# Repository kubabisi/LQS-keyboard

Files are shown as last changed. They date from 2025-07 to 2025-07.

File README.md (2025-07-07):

# LQS keyboard
**L**ow profile **Q**uiet **S**plit keyboard

## Why have I decided to build a keyboard?
A few years ago I received an 80% mechanical keyboard as a Christmas gift. It has been my daily driver since then.
But it has two issues:
1. It is too big and chunky to travel with or take it to school.
2. It is too loud. While it is quieter than some mechanical keyboards, you can easily hear it from the other side of my flat.

Since then Youtube algorithm has introduced me into the custom keyboard rabbit hole.
I've built a simple one using 3d printed parts and handwiring. It worked, but it was thick and after a few weeks it started to slowly break apart. First random solder joints started breaking, then the case cracked.

I wanted to build a proper keyboard, but I was too lazy to do it.
Highway gave me the motivation that I needed to finally do it.

## CAD model
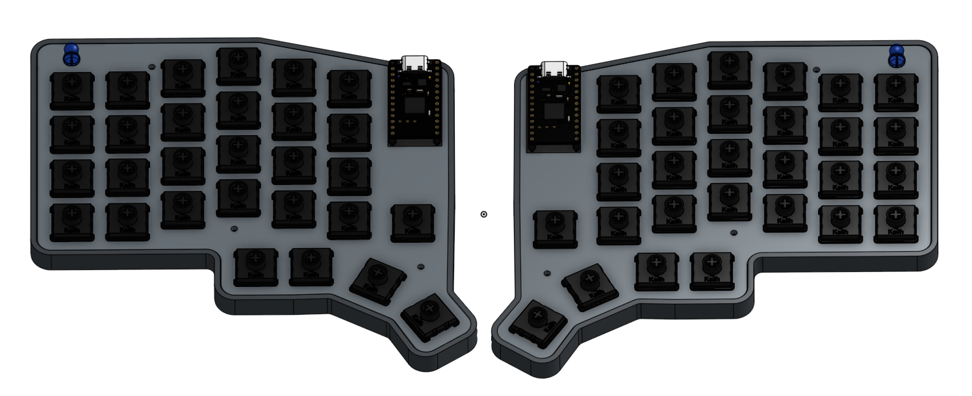
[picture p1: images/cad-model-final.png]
cad model

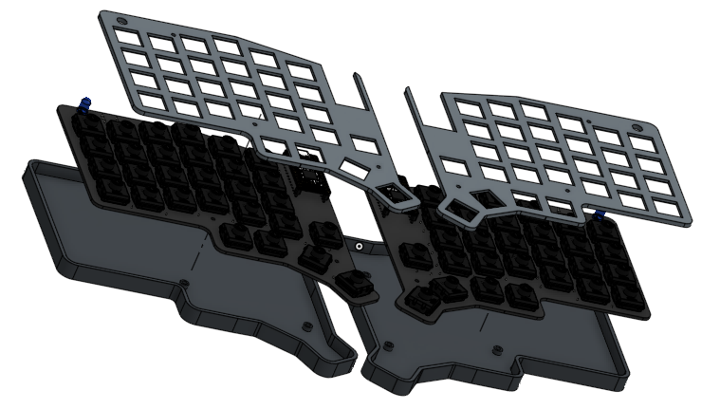
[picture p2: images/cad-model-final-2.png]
exploded cad model

[this model in Onshape](https://cad.onshape.com/documents/f682215273ff2081de69d414/w/20c4360147d88d6d7c704790/e/f61e22c6f2ff044978f79a00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)

## Switch layout
Switch layout was inspired by two keyboards I like: ZSA Voyager and Sofle
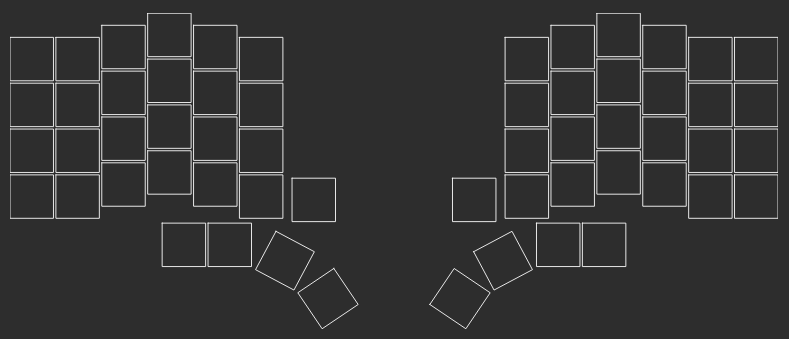
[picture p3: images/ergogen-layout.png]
layout in ergogen


## Schematic
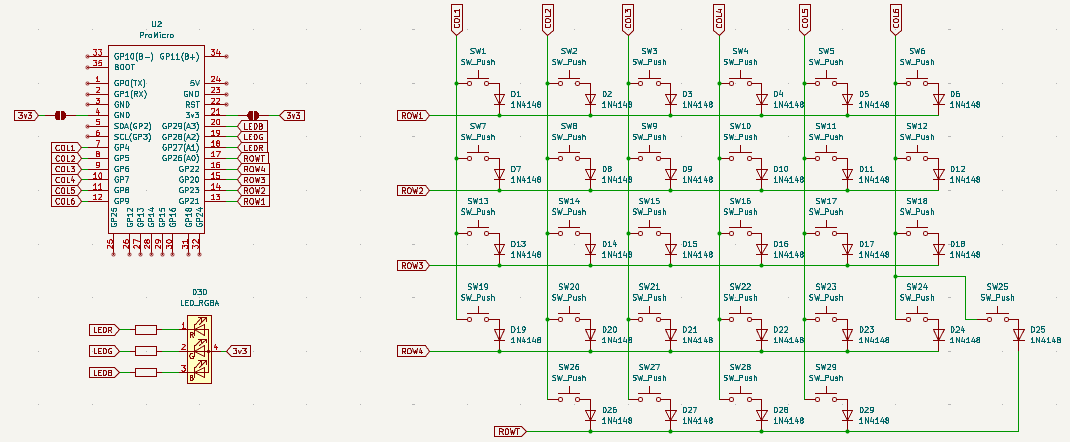
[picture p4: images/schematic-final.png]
keyboard half schematic


## PCB
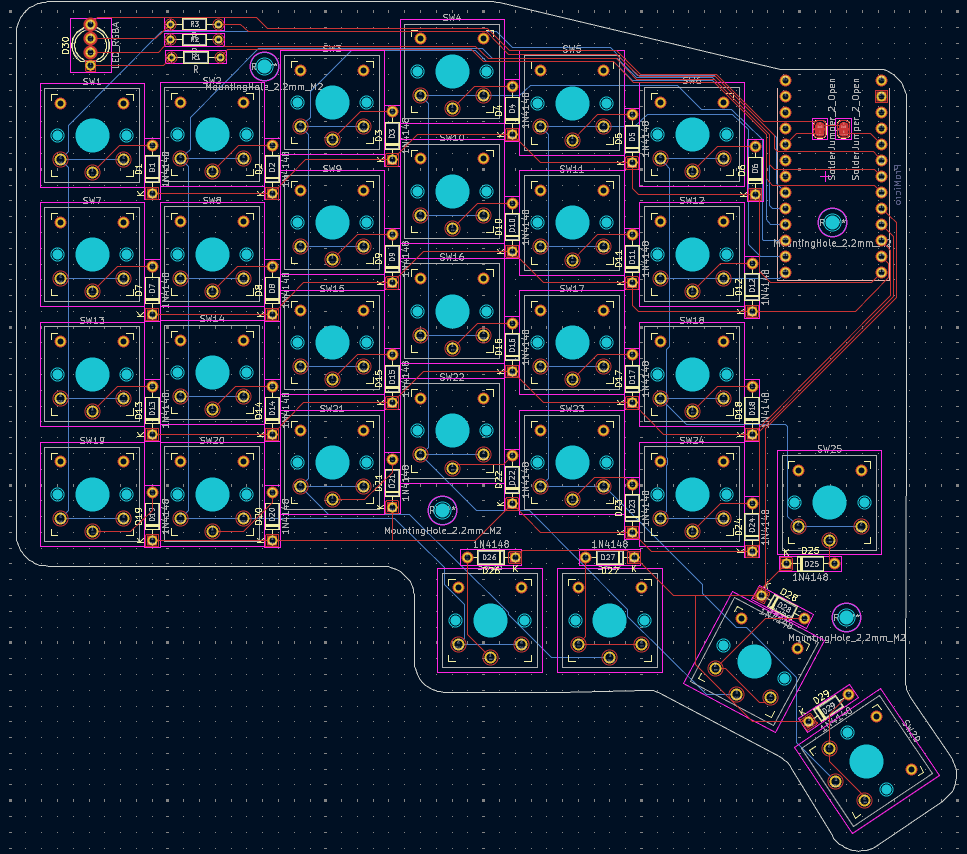
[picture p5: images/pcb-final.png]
keyboard half pcb


## Case
Case for this keyboard can be 3d printed. Stl files are located in [this folder](3d-models/case)

## BOM

| Part | Quantity | Cost(PLN) | Cost (USD) | Store | Link |
| --- | --- | --- | --- | --- | --- |
| Kailh Deep Sea Whale mini switches | 58 | 113.99 | 29.70 | Aliexpress | https://pl.aliexpress.com/item/1005008927866337.html |
| Pro Micro NRF52840 | 2 | 26.78 | 7.04 | Aliexpress | https://pl.aliexpress.com/item/1005006599766097.html |
| 301230 lipo battery | 2 | 45.25 | 11.70 | Allegro.pl | https://allegro.pl/oferta/akumulator-litowo-polimerowy-110mah-3-7v-phr-2-bk-301230-17500532114 |
| 1n4148 diodes | 58 | 5.55 | 1.47 | Aliexpress | https://pl.aliexpress.com/item/4000142272546.html |
| RGB common anode 5mm led | 2 | 3.99 | 1.05 | Aliexpress | https://pl.aliexpress.com/item/4000225253691.html |
| pin sockets | 52 pins - 2 rows | 7.10 | 1.87 | Aliexpress | https://pl.aliexpress.com/item/10000000838267.html |
| PCB | 5 | 41.80 | 11.60 | JLCPCB | https://jlcpcb.com/ |
| M2 6mm flat head screws | 8 | 3.62 | 0.96 | Aliexpress | https://pl.aliexpress.com/item/1005005270702287.html | 
| M2 3x3mm heat inserts | 8 | 5.6 | 1.47 | Aliexpress | https://pl.aliexpress.com/item/1005008295045821.html |
| resistors for leds | 6 | ~4 | ~1 | |  |
| keycap set | 1 | ~120 | ~35 | | |
| 3d printed case | 2 | | | | |

Total (excluding shipping): ~380 PLN / ~$105 USD

I already have keycaps and resistors. My brother has a 3d printer at home.

Total excluding parts I have, with shipping:
- $66.77 + $21.50 (JLCPCB shipping) + $0 (Aliexpress Choice free shipping) = $88.27
- 253,61zł + 77,63zł + 0zł = 331.24zł

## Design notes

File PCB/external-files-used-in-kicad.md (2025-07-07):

# footprints
- switch: https://github.com/siderakb/key-switches.pretty
- pro micro: https://github.com/Biacco42/ProMicroKiCad

# 3d models
- switch: https://github.com/koktoh/keyswitch_model
- nice!nano: https://grabcad.com/library/nice-nano-v2-1
- round pin socket: https://grabcad.com/library/straight-round-female-pin-header-2-54-mm-1

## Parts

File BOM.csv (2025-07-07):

part | quantity | cost(USD) | link
Kailh Deep Sea Whale mini switch | 58 | 29.70 | https://pl.aliexpress.com/item/1005008927866337.html
Pro Micro NRF52840 | 2 | 7.04 | https://pl.aliexpress.com/item/1005006599766097.html
301230 LiPo battery | 2 | 11.70 | https://allegro.pl/oferta/akumulator-litowo-polimerowy-110mah-3-7v-phr-2-bk-301230-17500532114
1n4148 diode | 58 | 1.47 | https://pl.aliexpress.com/item/4000142272546.html
RGB 5mm diode | 2 | 1.05 | https://pl.aliexpress.com/item/4000225253691.html
pin socket | 2 | 1.87 | https://pl.aliexpress.com/item/10000000838267.html
PCB | 5 | 11.60 | https://jlcpcb.com/
M2 6mm flat screw | 8 | 0.96 | https://pl.aliexpress.com/item/1005005270702287.html
M2 3x3mm heat insert | 8 | 1.47 | https://pl.aliexpress.com/item/1005008295045821.html
resistor | 6 | 1
keycap set | 1 | 35

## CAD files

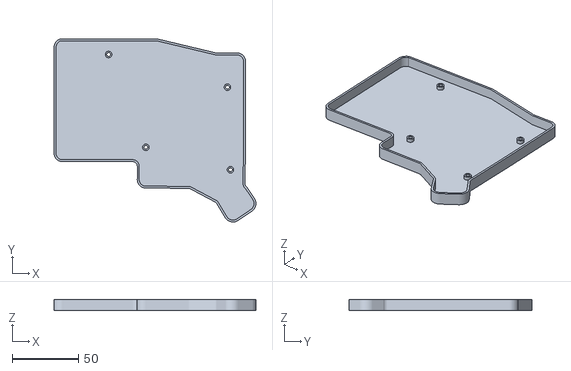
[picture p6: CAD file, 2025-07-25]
3d-models/case/left-shell.stl
152.9 x 138.6 x 8.50

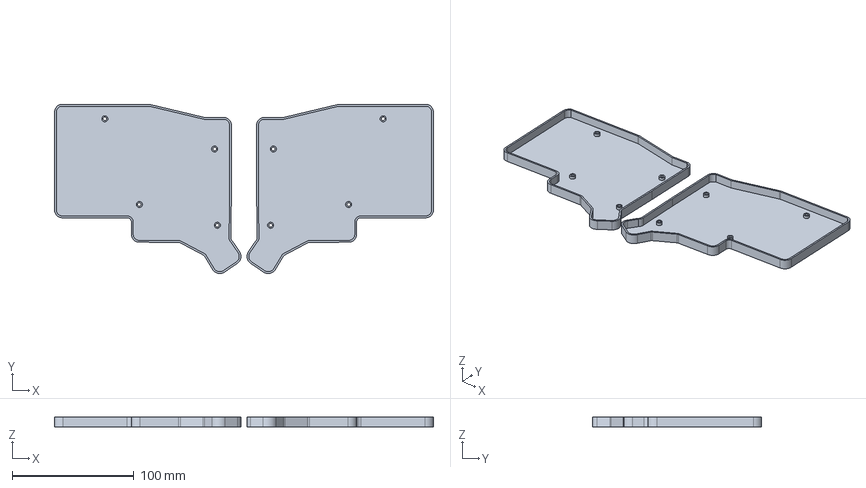
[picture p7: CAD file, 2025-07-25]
3d-models/step-files/shells.step
310.7 x 138.6 x 8.50 mm

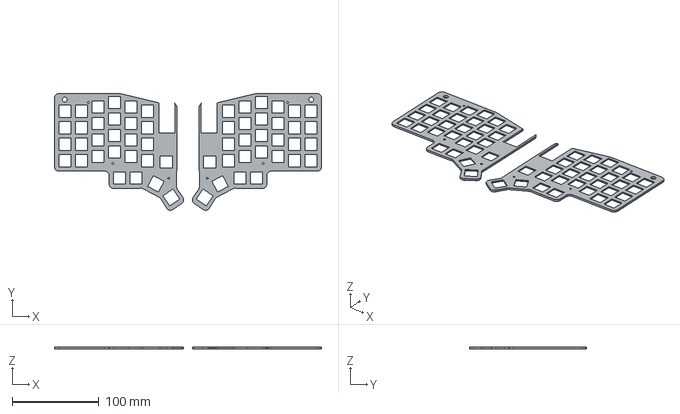
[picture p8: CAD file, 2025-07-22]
3d-models/step-files/plates.step
307.7 x 134.5 x 2.20 mm

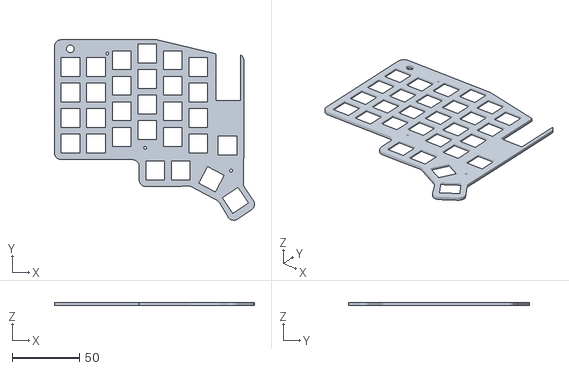
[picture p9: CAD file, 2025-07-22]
3d-models/case/left-plate.stl
148.9 x 134.5 x 2.20

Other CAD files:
3d-models/case/right-shell.stl
3d-models/case/right-plate.stl

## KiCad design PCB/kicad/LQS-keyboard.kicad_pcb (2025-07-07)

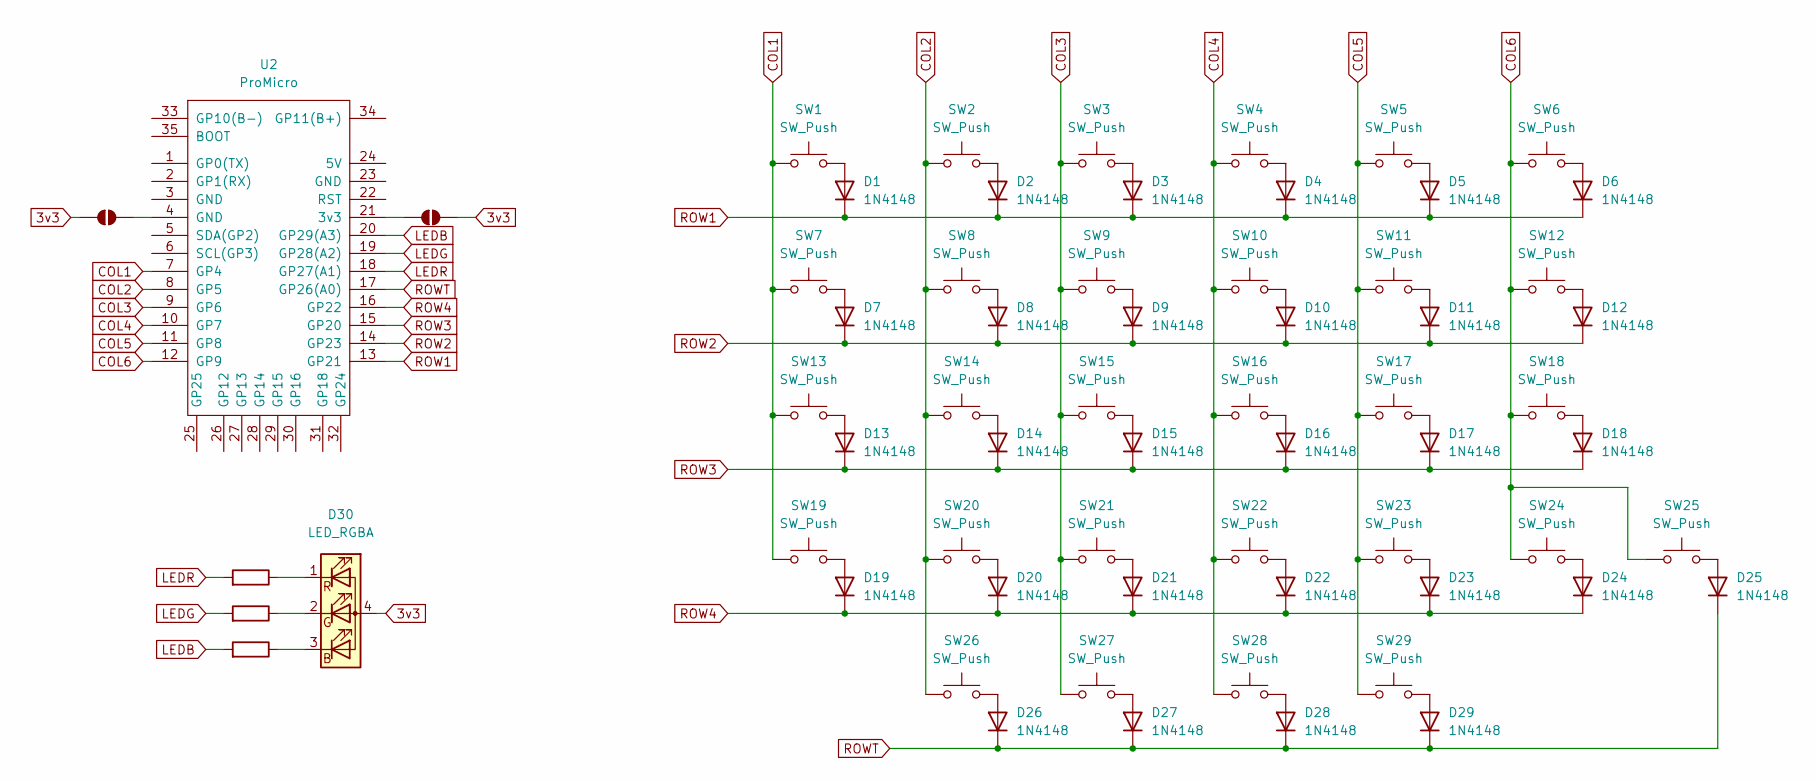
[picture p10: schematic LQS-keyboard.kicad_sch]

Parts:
D1, D2, D3, D4, D5, D6, D7, D8, D9, D10, D11, D12, D13, D14, D15, D16, D17, D18, D19, D20, D21, D22, D23, D24, D25, D26, D27, D28, D29: 1N4148; D_DO-35_SOD27_P7.62mm_Horizontal
D30: LED_RGBA; LED_D5.0mm-4_RGB
JP1, JP2: SolderJumper_2_Open; SolderJumper-2_P1.3mm_Open_RoundedPad1.0x1.5mm
R1, R2, R3: R; R_Axial_DIN0204_L3.6mm_D1.6mm_P7.62mm_Horizontal
SW1, SW2, SW3, SW4, SW5, SW6, SW7, SW8, SW9, SW10, SW11, SW12, SW13, SW14, SW15, SW16, SW17, SW18, SW19, SW20, SW21, SW22, SW23, SW24, SW25, SW26, SW27, SW28, SW29: SW_Push; SW_Kailh_Choc_V1V2_THT_Hybrid_doubleside
U2: ProMicro; TheOneProMicro

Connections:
3v3: D30.4 (A), JP1.2 (B), JP2.2 (B)
COL1: SW1.2, SW7.2, SW13.2, SW19.2, U2.7 (GP4)
COL2: SW2.2, SW8.2, SW14.2, SW20.2, SW26.2, U2.8 (GP5)
COL3: SW3.2, SW9.2, SW15.2, SW21.2, SW27.1, U2.9 (GP6)
COL4: SW4.2, SW10.2, SW16.2, SW22.2, SW28.1, U2.10 (GP7)
COL5: SW5.2, SW11.2, SW17.2, SW23.2, SW29.1, U2.11 (GP8)
COL6: SW6.2, SW12.2, SW18.2, SW24.2, SW25.2, U2.12 (GP9)
LEDB: R3.2, U2.20 (GP29(A3))
LEDG: R2.2, U2.19 (GP28(A2))
LEDR: R1.2, U2.18 (GP27(A1))
unnamed: D1.2 (A), SW1.1
unnamed: D2.2 (A), SW2.1
unnamed: D3.2 (A), SW3.1
unnamed: D4.2 (A), SW4.1
unnamed: D5.2 (A), SW5.1
unnamed: D6.2 (A), SW6.1
unnamed: D7.2 (A), SW7.1
unnamed: D8.2 (A), SW8.1
unnamed: D9.2 (A), SW9.1
unnamed: D10.2 (A), SW10.1
unnamed: D11.2 (A), SW11.1
unnamed: D12.2 (A), SW12.1
unnamed: D13.2 (A), SW13.1
unnamed: D14.2 (A), SW14.1
unnamed: D15.2 (A), SW15.1
unnamed: D16.2 (A), SW16.1
unnamed: D17.2 (A), SW17.1
unnamed: D18.2 (A), SW18.1
unnamed: D19.2 (A), SW19.1
unnamed: D20.2 (A), SW20.1
unnamed: D21.2 (A), SW21.1
unnamed: D22.2 (A), SW22.1
unnamed: D23.2 (A), SW23.1
unnamed: D24.2 (A), SW24.1
unnamed: D25.2 (A), SW25.1
unnamed: D26.2 (A), SW26.1
unnamed: D27.2 (A), SW27.2
unnamed: D28.2 (A), SW28.2
unnamed: D29.2 (A), SW29.2
unnamed: D30.3 (BK), R3.1
unnamed: D30.2 (GK), R2.1
unnamed: D30.1 (RK), R1.1
unnamed: JP1.1 (A), U2.4 (GND)
unnamed: JP2.1 (A), U2.21 (3v3)
ROW1: D1.1 (K), D2.1 (K), D3.1 (K), D4.1 (K), D5.1 (K), D6.1 (K), U2.13 (GP21)
ROW2: D7.1 (K), D8.1 (K), D9.1 (K), D10.1 (K), D11.1 (K), D12.1 (K), U2.14 (GP23)
ROW3: D13.1 (K), D14.1 (K), D15.1 (K), D16.1 (K), D17.1 (K), D18.1 (K), U2.15 (GP20)
ROW4: D19.1 (K), D20.1 (K), D21.1 (K), D22.1 (K), D23.1 (K), D24.1 (K), U2.16 (GP22)
ROWT: D25.1 (K), D26.1 (K), D27.1 (K), D28.1 (K), D29.1 (K), U2.17 (GP26(A0))

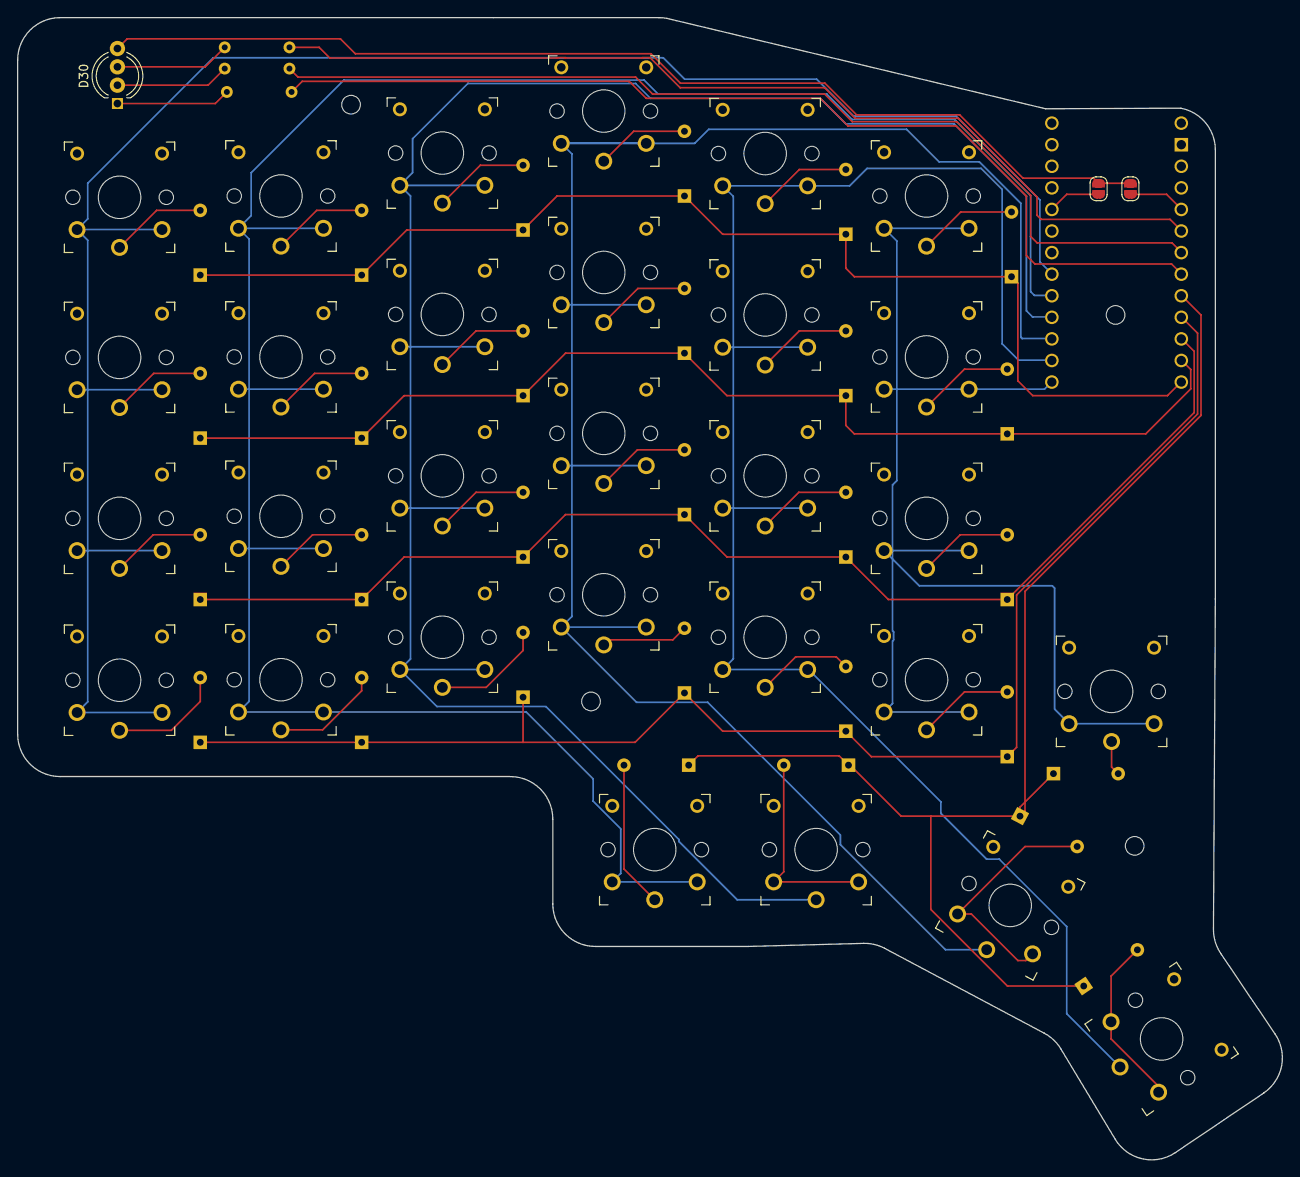
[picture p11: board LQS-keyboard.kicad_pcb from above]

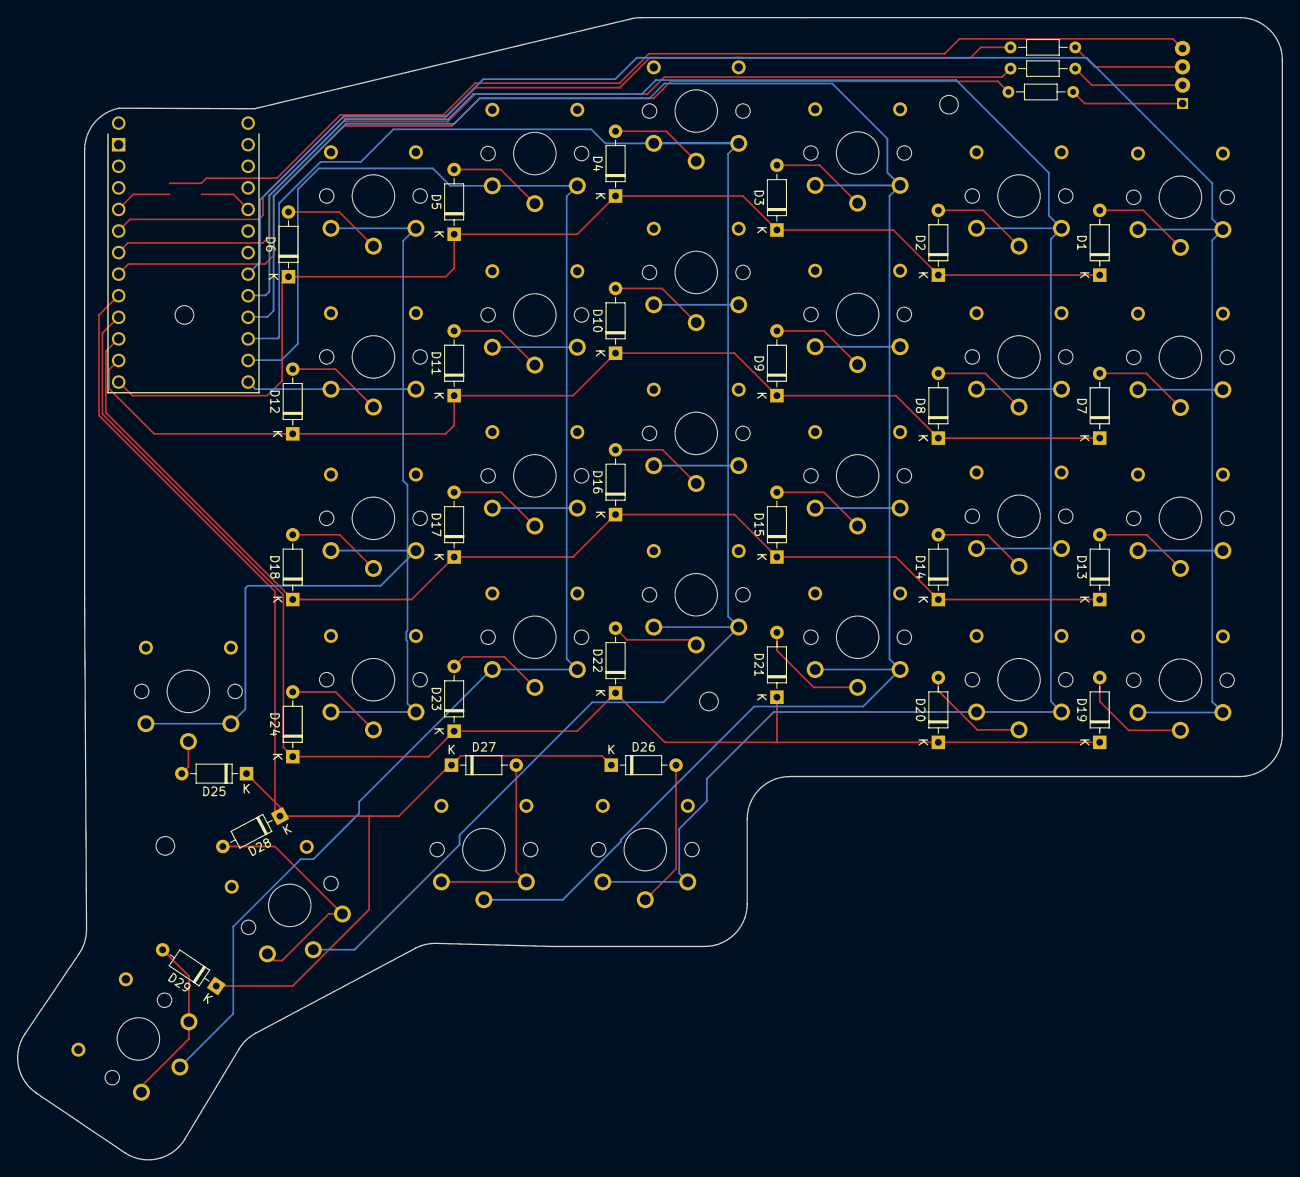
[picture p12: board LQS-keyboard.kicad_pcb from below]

Board: 2 copper layers, 148.9 x 134.5 mm, 65 parts (32 on the bottom side), 49 nets.

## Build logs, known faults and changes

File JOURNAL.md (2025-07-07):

---
title: "LQS keyboard"
author: "kubabisi"
description: "Silent low profile custom split keyboard"
created_at: "2025-07-01"
---
Total time spent so far: ~21 hours

# July 1st: Brainstorming and pcb
I started by listing what my keyboard needs to have:
- quiet
- as slim as posible, while being durable to fit in my school bag
- tactile switches - I've tested linear swithes on keyboards in tech shops, but I don't like them - lack of feedback makes me misstype more often
- ~50 keys (number row, 6th column and thumb keys)
- wireless
- usb-c (nearly every device I am using is using it)

Then I searched for switches that would fit in those requirements and I've found them - Kailh Deep Sea Whale mini switches.

Having a list of requirements and switches I started designing.

First I designed the layout in Ergogen. I've used it to make my first keyboard, so I already knew what to do and what I need.
layout in ergogen

Once I was happy with the key layout, I started designing the actual circuit. 
BTW: This was my first time using Kicad and designing pcbs.

I've choosen Seeed Studio XIAO nRF52840 as the microcontroller as I want to use ZMK as firmware.

Because I wanted to use Choc v2 switches and Seeed XIAO mcu I needed to find required kicad files before doing anything.
Quickly I've found siderakb's switch footprints and oficial XIAO kicad files.

Schematic is simple. Just switches, diodes and microcontroller. I've also added jumpers to make one pcb for both halves.
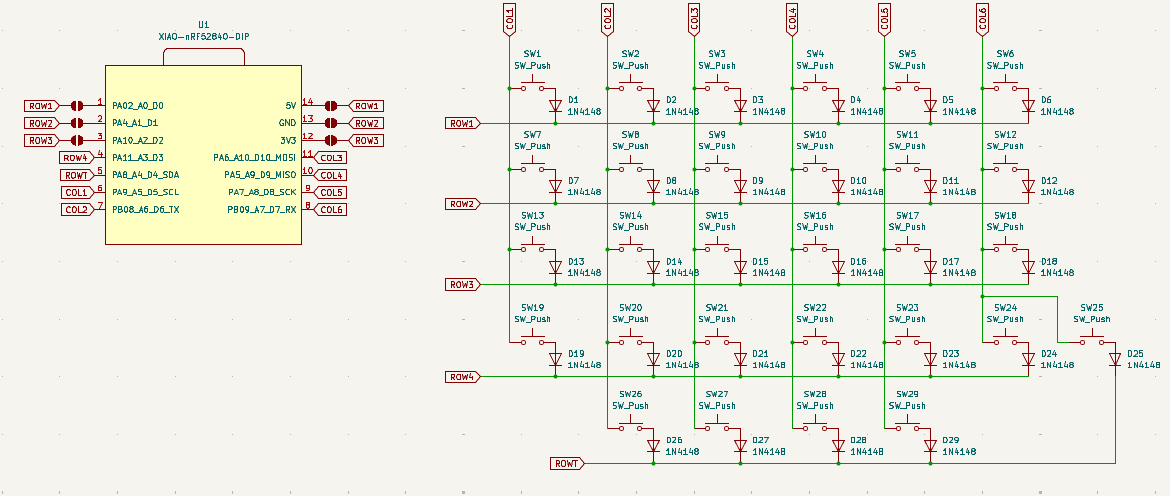
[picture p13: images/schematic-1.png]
schematic


Then came the time for the pcb. Ergogen generated a base pcb, but I needed to swap all switch footprints to the right ones. (Only later I've read on the Highway website that there is a tool that would have done that for me)

PCB design isn't as hard as I thought, but it is tedious. While I don't think that my pcb is great, it should work just fine.
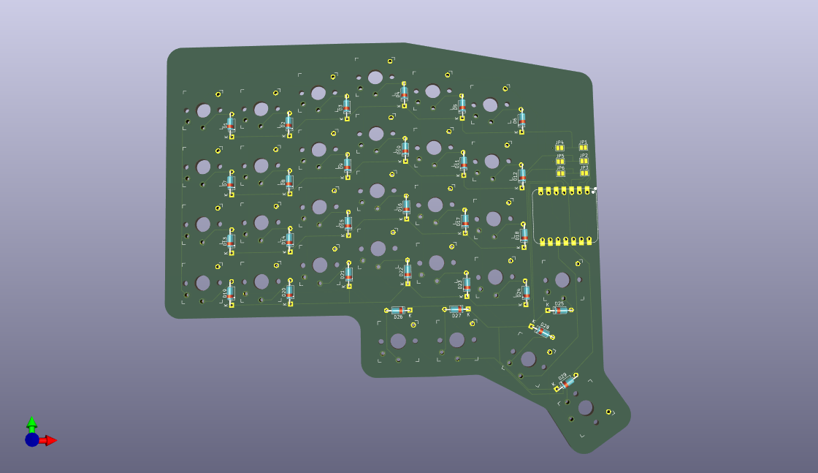
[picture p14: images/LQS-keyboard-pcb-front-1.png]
pcb front

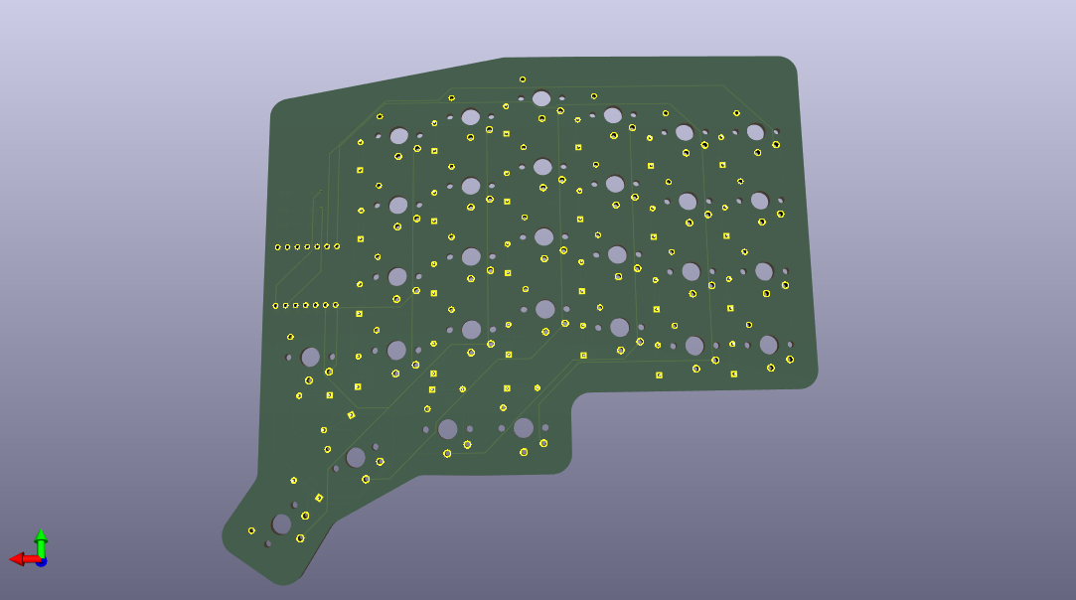
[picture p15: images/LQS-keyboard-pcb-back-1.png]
pcb back


Total time spent: ~8 hours

# July 5th: PCB changes and BOM

While looking for parts on Aliexpress I found cheaper mcu - clones of nice!nano v2, and I decided to use them instead of XIAOs.
Also I realised that to make the PCB reversible I also needed to modify key switch footprints.
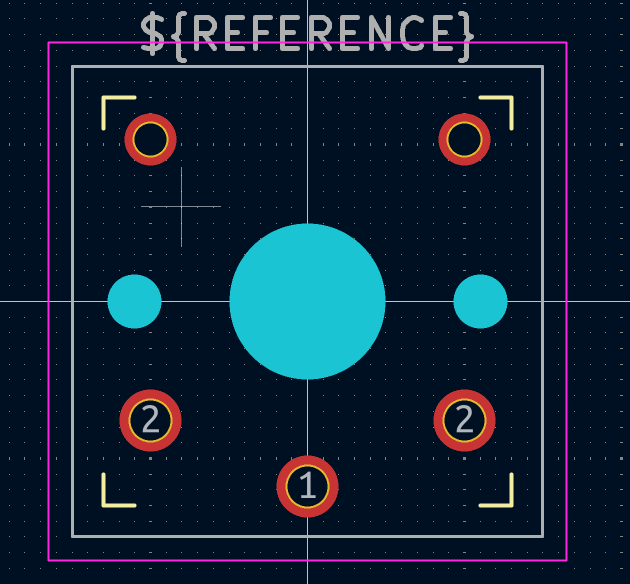
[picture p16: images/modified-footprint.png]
modified footprint


Which meant rewiring was required - yay! /s

While rewiring I also added an RGB led indicator (XIAO has one bulit in, but n!n doesn't).

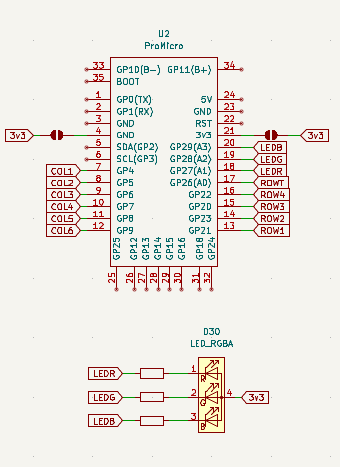
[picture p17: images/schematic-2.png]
changes in schematic

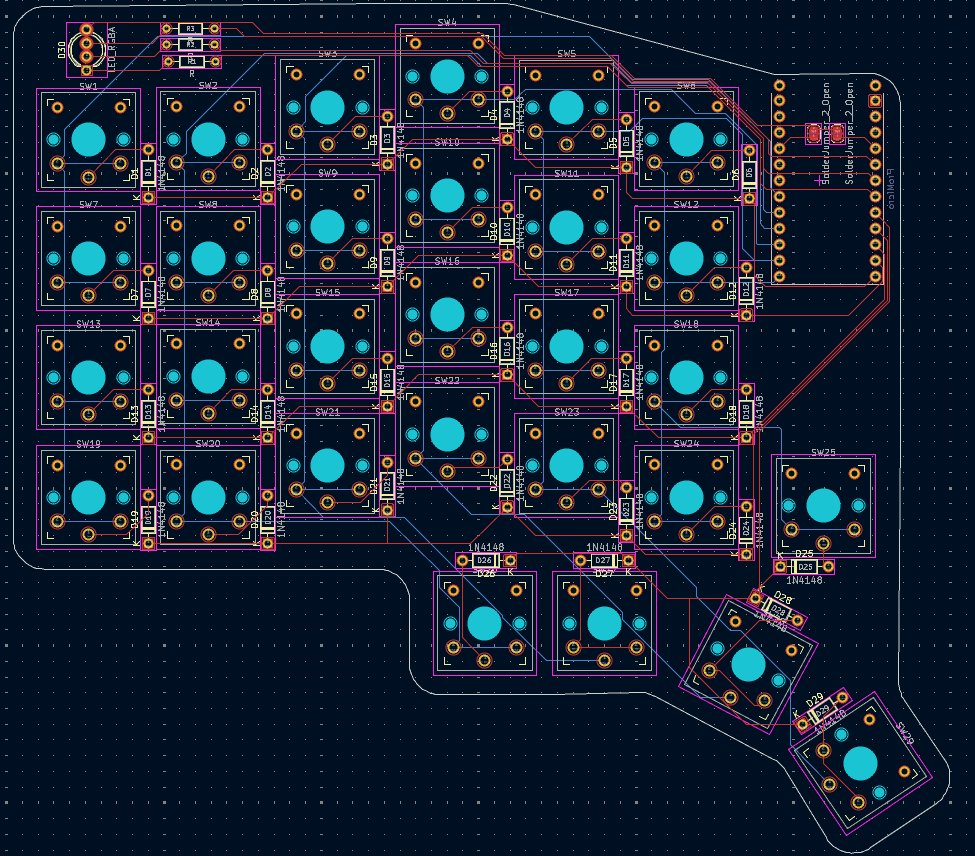
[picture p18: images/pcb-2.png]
current pcb


Total time spent: ~3 hours

# July 6th: case

Today I worked on shells for each keyboard half.

I used Onshape for this. It was my first time using a proper CAD software (earlier I only used Tinkercad). While I quickly learned basics, I still don't know what most of its tools do.

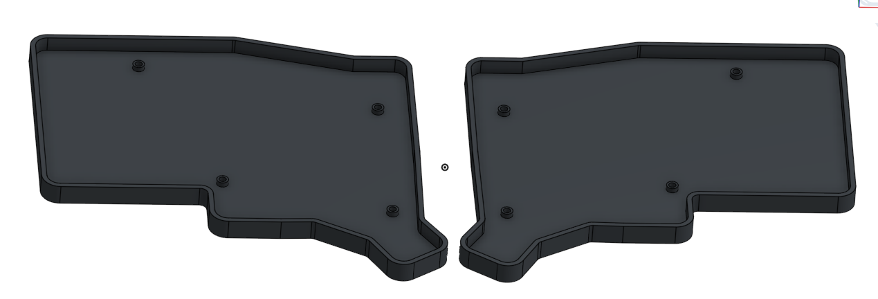
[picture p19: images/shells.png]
shells

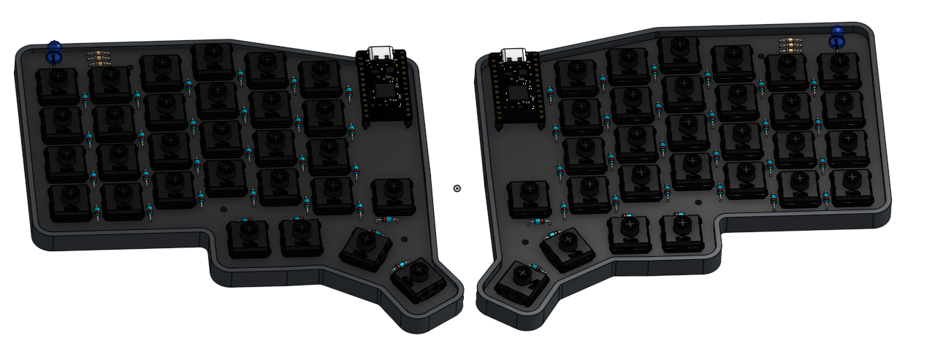
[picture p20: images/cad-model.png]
whole keyboard in CAD


Today I also searched for parts, filled out the BOM and calculated prices for everyting.

Total time spent: ~6 hours

# July 7th: firmware and case pt.2

I decided to modify the case to add a plate for the switches.
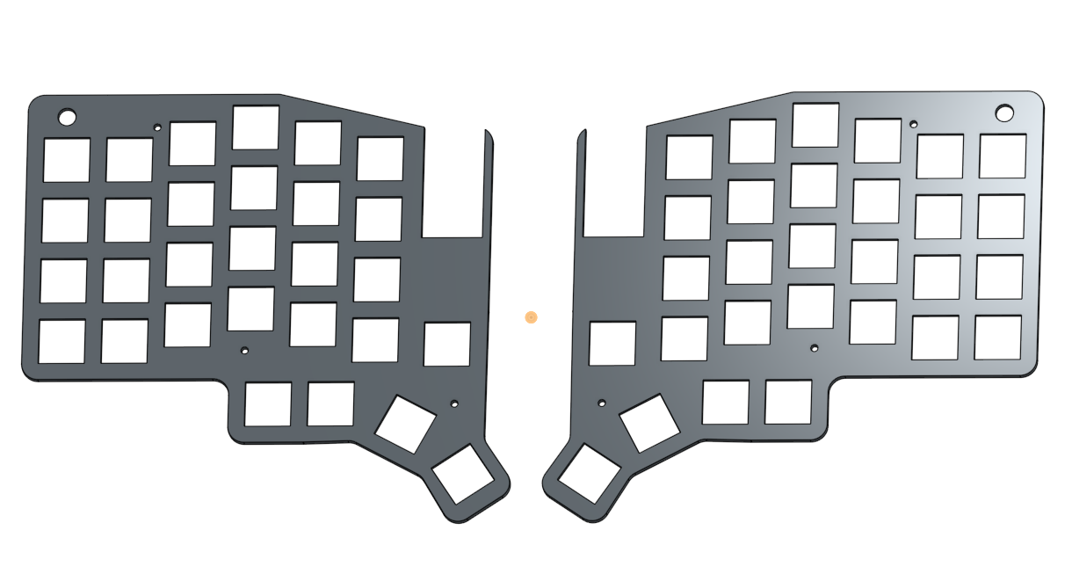
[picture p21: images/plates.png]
plates

whole keyboard

Today I mostly worked on the ZMK firmware configuration.
I followed the guide from ZMK's docs.

After completing it and fixing a few small errors, I've got it to successfully compile.

Total time spent: ~4 hours

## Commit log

2025-07-05 2025-07-05 update
    [LQS-keyboard-B_Cu.gbr, LQS-keyboard-B_Mask.gbr, LQS-keyboard-B_Paste.gbr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]
2025-07-06 2025-07-06 update
    [LQS-keyboard-B_Cu.gbr, LQS-keyboard-B_Mask.gbr, LQS-keyboard-B_Paste.gbr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]
2025-07-07 documentation update
    [BOM.csv, LQS-keyboard-right.kicad_pcb, LQS-keyboard.kicad_pcb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]
2025-07-07 2025-07-07 update
    [LQS-keyboard-right.kicad_pcb, LQS-keyboard.kicad_pcb, left_keys.dxf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]
2025-07-07 documentation update
    add missing stl files, add total time
    [left plate.stl, right plate.stl]
2025-07-07 3d model files reorganization
    [left-plate.stl, left-shell.stl, left_keys.dxf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]
2025-07-07 add list of external files for kicad
2025-07-07 small BOM update
    screws need to be longer to screw through the plate
    [BOM.csv]
2025-07-07 change screw length in readme
2025-07-21 shells are now a bit thinner
    2mm -> 1.2mm
    [left-shell.stl, right-shell.stl, shells.step]
2025-07-22 increase led hole size
    5mm -> 5.7mm
    [left-plate.stl, plates.step, right-plate.stl]
2025-07-24 slightly increase heat insert standoffs size
    [left-shell.stl, right-shell.stl, shells.step]
2025-07-25 slightly increase gap between shell and pcb/plate
    [left-shell.stl, right-shell.stl, shells.step]
